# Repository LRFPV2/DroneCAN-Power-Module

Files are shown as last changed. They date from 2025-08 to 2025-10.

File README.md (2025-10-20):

# XRC Technologies DroneCAN Power Module

INSTRUCTIONS FOR USE: 
Checkout code and submodules. If sub-modules are not checked out, code will not compile properly due to broken dependencies.
```
git clone --recurse-submodules https://github.com/LRFPV2/DroneCAN-Power-Module.git
```
To flash to device, open project in PlatformIO and build "Micro-Node-No-Bootloader"

Go into STM32CubeIDE and open the file "firmware.bin" from folder .pio

Select "Download" to program to STM32 after connecting.

Version 2.0 to be released soon at https://xrctechnologies.com/


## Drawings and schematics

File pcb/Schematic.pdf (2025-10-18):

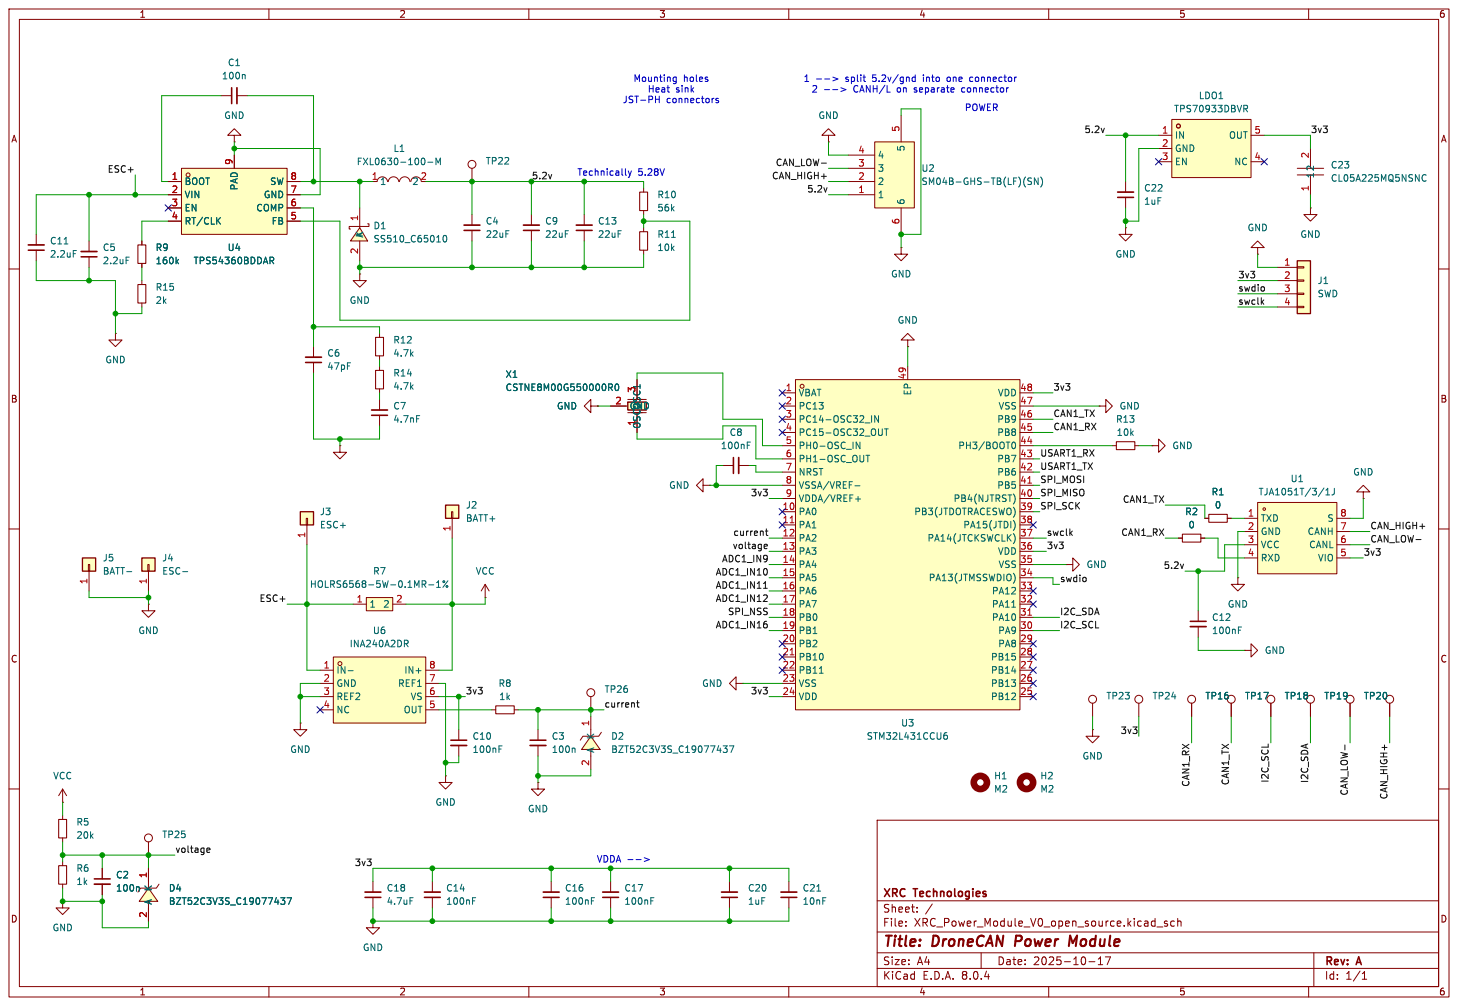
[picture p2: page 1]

Mounting holes Heat sink
ADC1_IN9 CAN_LOW- CAN_HIGH+

10k GND GND GND GND

6 U2SM04B-GHS-TB(LF)(SN) GND

Id: 1/1 Title: DroneCAN Power Module

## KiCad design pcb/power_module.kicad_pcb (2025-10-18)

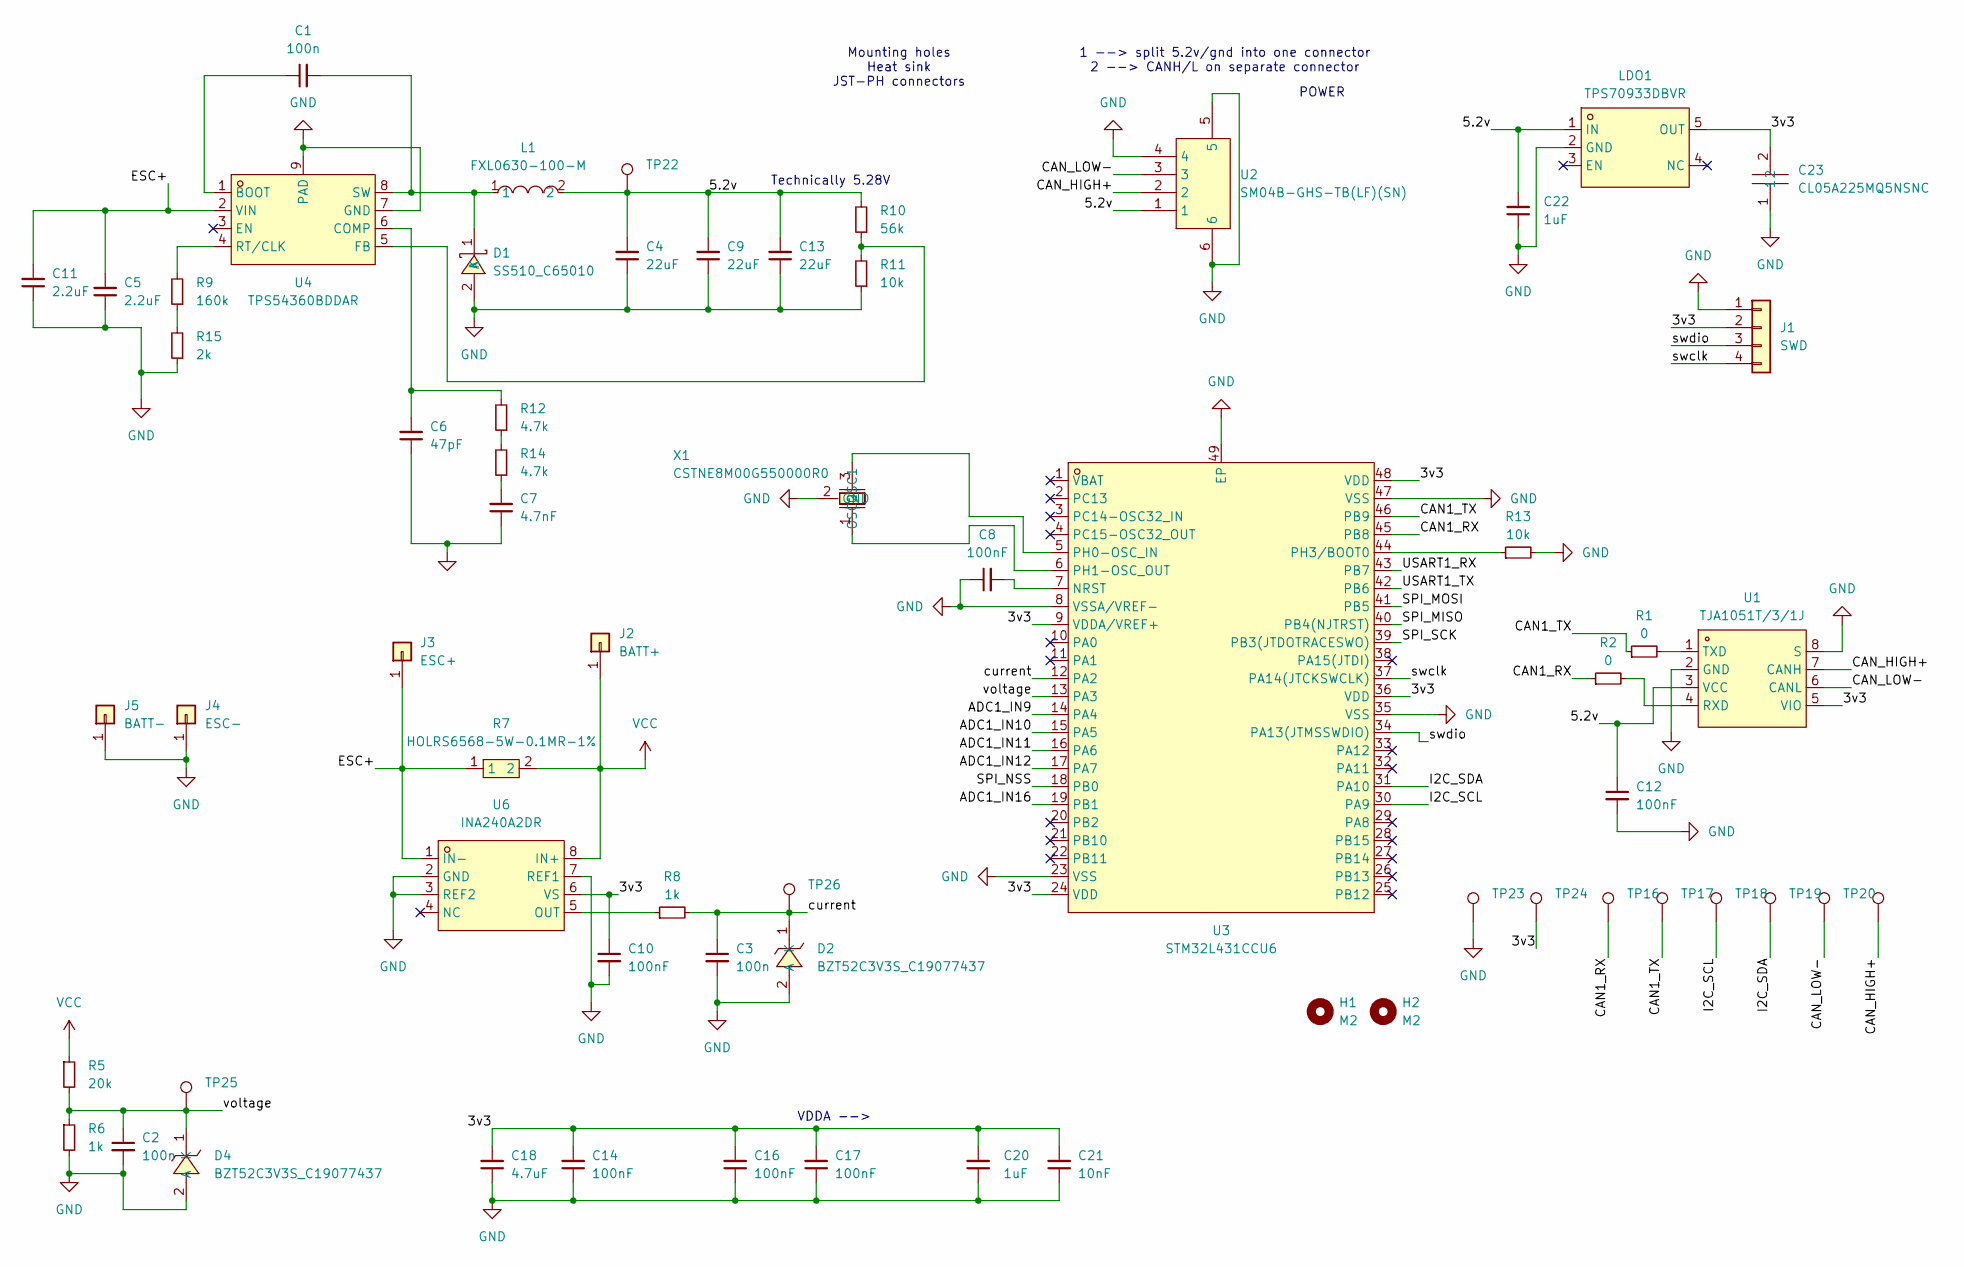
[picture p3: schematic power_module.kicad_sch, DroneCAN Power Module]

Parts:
C1, C2, C3: 100n; C_0402_1005Metric
C4, C9, C13: 22uF; C_0805_2012Metric
C5, C11: 2.2uF; C_1210_3225Metric
C6: 47pF; C_0402_1005Metric
C7: 4.7nF; C_0402_1005Metric
C8, C10, C12, C14, C16, C17: 100nF; C_0402_1005Metric
C18: 4.7uF; C_0402_1005Metric
C20, C22: 1uF; C_0402_1005Metric
C21: 10nF; C_0402_1005Metric
C23: CL05A225MQ5NSNC; C0402; LCSC Part C12530
D1: SS510_C65010; SMA_L4.3-W2.6-LS5.2-RD; LCSC Part C65010
D2, D4: BZT52C3V3S_C19077437; SOD-323_L1.7-W1.3-LS2.6-RD; LCSC Part C19077437
H1, H2: M2; MountingHole_2.2mm_M2
J1: SWD; PinHeader_1x04_P1.00mm_Vertical
J2: BATT+; Big-pad-0
J3: ESC+; Big-pad-0
J4: ESC-; Big-pad-0
J5: BATT-; Big-pad-0
L1: FXL0630-100-M; IND-SMD_L7.3-W6.8; LCSC Part C167223
LDO1: TPS70933DBVR; SOT-23-5_L3.0-W1.7-P0.95-LS2.8-BR; LCSC Part C89347
R1, R2: 0; R_0402_1005Metric
R5: 20k; R_0603_1608Metric
R6, R8: 1k; R_0402_1005Metric
R7: HOLRS6568-5W-0.1MR-1%; RES-SMD_L6.9-W6.6-A; LCSC Part C2927618
R9: 160k; R_0603_1608Metric
R10: 56k; R_0805_2012Metric
R11, R13: 10k; R_0402_1005Metric
R12, R14: 4.7k; R_0603_1608Metric
R15: 2k; R_0603_1608Metric
TP16, TP17, TP18, TP19, TP20, TP21, TP22, TP23, TP24, TP25, TP26: TestPoint_Pad_D1.0mm
U1: TJA1051T/3/1J; SOIC-8_L4.9-W3.9-P1.27-LS6.0-BL; LCSC Part C38695
U2: SM04B-GHS-TB(LF)(SN); CONN-SMD_4P-P1.25_SM04B-GHS-TB-LF-SN; LCSC Part C189895
U3: STM32L431CCU6; VQFN-48_L7.0-W7.0-P0.50-BL-EP5.5; LCSC Part C1337258
U4: TPS54360BDDAR; SOIC-8_L5.0-W4.0-P1.27-LS6.0-BL-EP2.0; LCSC Part C524806
U6: INA240A2DR; SOIC-8_L4.9-W3.9-P1.27-LS6.0-BL; LCSC Part C2060768
X1: CSTNE8M00G550000R0; OSC-SMD_3P-L3.2-W1.3-P1.20-L; LCSC Part C341522

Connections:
/3v3: C10.1, C14.2, C16.2, C17.2, C18.2, C20.2, C21.2, C23.2, J1.2, LDO1.5 (OUT), TP24.1, U1.5 (VIO), U3.9 (VDDA/VREF+), U3.24 (VDD), U3.36 (VDD), U3.48 (VDD), U6.6 (VS)
/5.2v: C4.2, C9.2, C12.1, C13.2, C22.2, L1.2, LDO1.1 (IN), R10.2, TP22.1, U1.3 (VCC), U2.1
/ADC1_IN9: U3.14 (PA4)
/ADC1_IN10: U3.15 (PA5)
/ADC1_IN11: U3.16 (PA6)
/ADC1_IN12: U3.17 (PA7)
/ADC1_IN16: U3.19 (PB1)
/CAN1_RX: R2.1, TP16.1, U3.45 (PB8)
/CAN1_TX: R1.1, TP17.1, U3.46 (PB9)
/CAN_HIGH+: TP21.1, U1.7 (CANH), U2.2
/CAN_LOW-: TP20.1, U1.6 (CANL), U2.3
/ESC+: C5.2, C11.2, J3.1, R7.1, U4.2 (VIN), U6.1 (IN-)
/I2C_SCL: TP18.1, U3.30 (PA9)
/I2C_SDA: TP19.1, U3.31 (PA10)
/SPI_MISO: U3.40 (PB4(NJTRST))
/SPI_MOSI: U3.41 (PB5)
/SPI_NSS: U3.18 (PB0)
/SPI_SCK: U3.39 (PB3(JTDOTRACESWO))
/USART1_RX: U3.43 (PB7)
/USART1_TX: U3.42 (PB6)
/current: C3.1, D2.1 (K), R8.2, TP26.1, U3.12 (PA2)
/swclk: J1.4, U3.37 (PA14(JTCKSWCLK))
/swdio: J1.3, U3.34 (PA13(JTMSSWDIO))
/voltage: C2.1, D4.1 (K), R5.2, R6.1, TP25.1, U3.13 (PA3)
GND: C2.2, C3.2, C4.1, C5.1, C6.1, C7.1, C8.1, C9.1, C10.2, C11.1, C12.2, C13.1, C14.1, C16.1, C17.1, C18.1, C20.1, C21.1, C22.1, C23.1, D1.2 (A), D2.2 (A), D4.2 (A), J1.1, J4.1, J5.1, LDO1.2 (GND), R6.2, R11.1, R13.2, R15.1, TP23.1, U1.2 (GND), U1.8 (S), U2.4, U2.5, U2.6, U3.8 (VSSA/VREF-), U3.23 (VSS), U3.35 (VSS), U3.47 (VSS), U3.49 (EP), U4.7 (GND), U4.9 (PAD), U6.2 (GND), U6.3 (REF2), U6.7 (REF1), X1.2 (GND)
unnamed: C7.2, R14.1
unnamed: C1.2, D1.1 (K), L1.1, U4.8 (SW)
unnamed: R12.1, R14.2
unnamed: R9.1, R15.2
unnamed: R2.2, U1.4 (RXD)
unnamed: R1.2, U1.1 (TXD)
unnamed: C8.2, U3.7 (NRST)
unnamed: U3.5 (PH0-OSC_IN), X1.3 (OSC2)
unnamed: U3.6 (PH1-OSC_OUT), X1.1 (OSC1)
unnamed: R13.1, U3.44 (PH3/BOOT0)
unnamed: C1.1, U4.1 (BOOT)
unnamed: C6.2, R12.2, U4.6 (COMP)
unnamed: R10.1, R11.2, U4.5 (FB)
unnamed: R9.2, U4.4 (RT/CLK)
unnamed: R8.1, U6.5 (OUT)
VCC: J2.1, R5.1, R7.2, U6.8 (IN+)

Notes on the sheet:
Mounting holes Heat sink JST-PH connectors
Technically 5.28V
POWER
VDDA -->
1 --> split 5.2v/gnd into one connector 2 --> CANH/L on separate connector

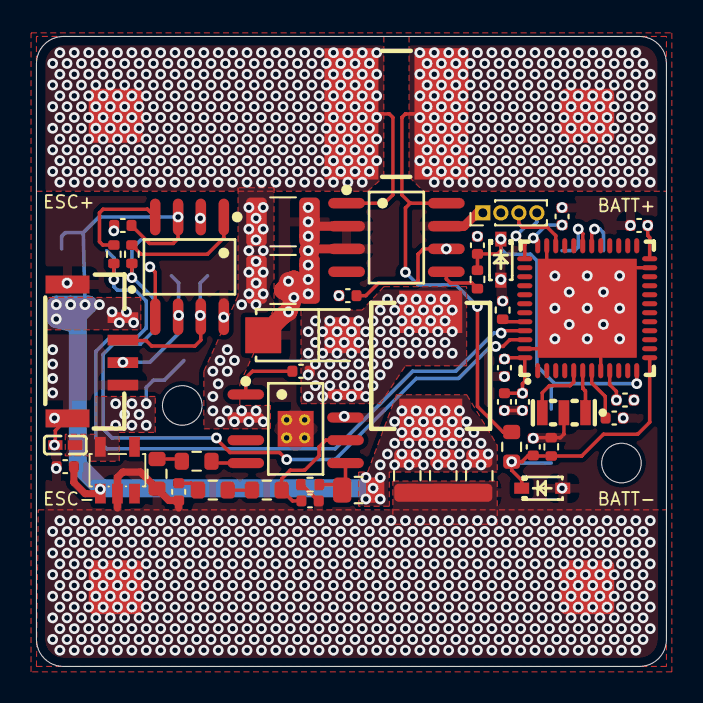
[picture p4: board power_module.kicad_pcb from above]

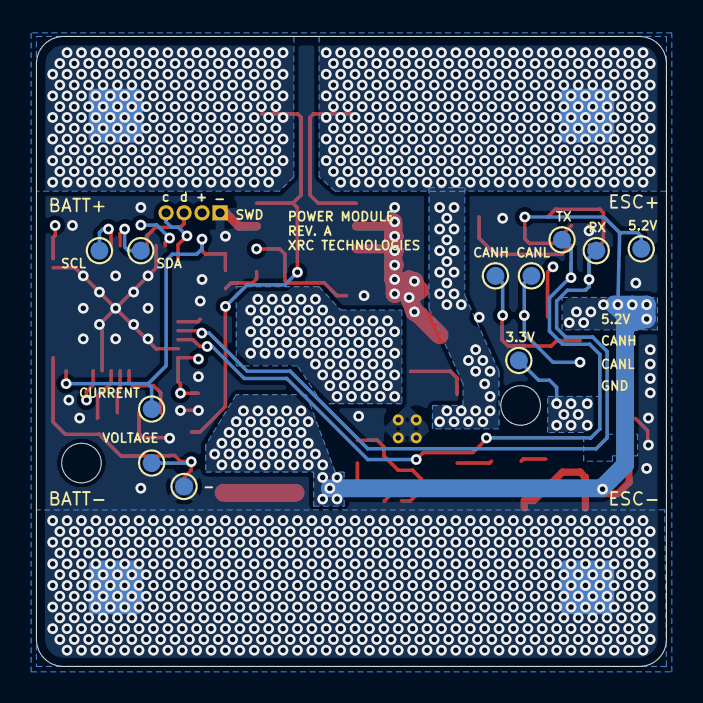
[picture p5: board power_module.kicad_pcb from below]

Board: 6 copper layers, 35.0 x 35.0 mm, 63 parts (11 on the bottom side), 30 nets.

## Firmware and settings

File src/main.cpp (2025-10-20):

// XRC Technologies DroneCAN Power Module

#include <Arduino.h>
#include <dronecan.h>
#include <IWatchdog.h>
#include <app.h>
#include <vector>
#include <simple_dronecanmessages.h>

// Calculations:
// 0.1mOhm resistor
// 20k-1k voltage divider
// Vout = Vbatt / 21
// 12-bit ADC (4096 bit resolution)
// INA240A2 --> 50V/V Gain
// Voltage (ADC)= I * 0.0001 * 50 = 3.3/4096
// Voltage (ADC) = 3.3/4096 = V_batt / 21
// Target current: 200A
// These are good starting numbers but actual numbers may vary
// I_batt = 0.0064453125 * V_adc
// V_batt = 0.0169189453125 * V_adc
// 1 / I_batt constant = 155.151515
// 1 / V_batt constant = 59.1053391

#define SHUNT_RESISTANCE 0.0025
#define CURRENT_SCALE_FACTOR 1.623
#define VOLTAGE_SCALE_FACTOR 14.705
#define CURRENT_PIN PA2
#define VOLTAGE_PIN PA3

float current;
float voltage;

std::vector<DroneCAN::parameter> custom_parameters = {
    {"NODEID", UAVCAN_PROTOCOL_PARAM_VALUE_INTEGER_VALUE, 127, 0, 127}};

DroneCAN dronecan;

uint32_t looptime = 0;

static void onTransferReceived(CanardInstance *ins, CanardRxTransfer *transfer)
{
    DroneCANonTransferReceived(dronecan, ins, transfer);
}

static bool shouldAcceptTransfer(const CanardInstance *ins,
                                 uint64_t *out_data_type_signature,
                                 uint16_t data_type_id,
                                 CanardTransferType transfer_type,
                                 uint8_t source_node_id)

{
    return false || DroneCANshoudlAcceptTransfer(ins, out_data_type_signature, data_type_id, transfer_type, source_node_id);
}

void setup()
{
    app_setup();
    IWatchdog.begin(2000000); 
    Serial.begin(115200);
    dronecan.version_major = 1;
    dronecan.version_minor = 0;
    dronecan.init(
        onTransferReceived, 
        shouldAcceptTransfer, 
        custom_parameters,
        "XRC Technologies Power Module"
    );
    pinMode(CURRENT_PIN, INPUT);
    pinMode(VOLTAGE_PIN, INPUT);

    while (true)
    {
        const uint32_t now = millis();

        // send our battery message at 10Hz
        if (now - looptime > 100)
        {
            looptime = millis();

            // construct dronecan packet
            current = analogRead(CURRENT_PIN) / CURRENT_SCALE_FACTOR;
            voltage = analogRead(VOLTAGE_PIN) / VOLTAGE_SCALE_FACTOR;
            uavcan_equipment_power_BatteryInfo pkt{};
            pkt.voltage = voltage;
            pkt.current = current;
            //pkt.temperature = INA.getTemperature();

            sendUavcanMsg(dronecan.canard, pkt);
        }

        dronecan.cycle();
        IWatchdog.reload();
    }
}

void loop()
{
    // Doesn't work coming from bootloader ? use while loop in setup
}

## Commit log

2025-05-07 1.2 (#7)
    * bring in 1.2 library changes
    * Update ArduinoDroneCANlib reference to 1.2
2025-06-15 1.3 library changes (#12)
    - Allow bootloaderless switching
    - force node allocation in library initialisation to make sure we get CAN connection before user code has opportunity to crash
    - Fix node id bug on a new node
    - Format, restructure and add comments
    - Add simple messages support
    * 1.2.1 library changes
    * update submodule
    * add in 1.3 variant
    * platformio config bootloader options
    * Update lib git reference
    [main.cpp]
2025-07-21 Integrate DNA bug fix (#20)
    [main.cpp]
2025-10-18 Added schematic
2025-10-18 Added hardware design files
    [power_module.kicad_pcb, power_module.kicad_sch]
2025-10-20 Calibrated scaling facotrs
